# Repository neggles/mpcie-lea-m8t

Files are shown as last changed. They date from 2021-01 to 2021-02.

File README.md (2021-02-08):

# mPCIe-LEA-M8T


This is a little miniPCIe card I designed to hold a [u-blox LEA-M8T](https://www.u-blox.com/en/product/neolea-m8t-series) GNSS module, with an IO header and an optional backup supercap.
The IO header has both timepulse outputs, as well as UART TX/RX. Module USB is connected to miniPCIe USB. I have not included a way to switch from UART to SPI.

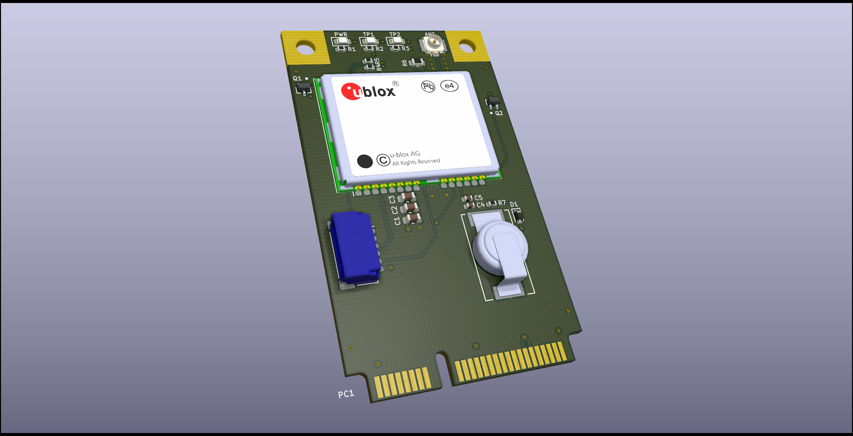
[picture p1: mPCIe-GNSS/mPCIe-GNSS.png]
KiCad raytraced board render


I had this made by [JLCPCB](https://jlcpcb.com) using their 1mm thick PCBs, and elected to get them to assemble most of it - while all of the parts except the supercapacitor, connectors, and GNSS module are in their extended part library, it didn't make sense to spend $6 on extended part fees for two assembled boards, so I skipped the transistors and diode.

## Repository Structure
- `mPCIe-GNSS` contains the main schematics and board drawing
- `mPCIe-GNSS/mPCIe-GNSS.pretty` contains the board-specific footprints
- `mPCIe-GNSS/mPCIe-GNSS-archive.lib` contains the board-specific symbols

## Building
Simply call `make` in the top-top level directory. The `build` directory will
them contain:

- the main mPCIe board
- A panelized version of said board
- zipped gerbers for the boards you can directly use for manufacturing
- zipped gerbers and SMT assembly BOM/position files for JLCPCB's SMT assembly service for the single-board version.

Makefile uses [Jan Mrázek](https://github.com/yaqwsx)'s [KiKit](https://github.com/yaqwsx/KiKit), which I cannot recommend enough, and therefore has to be available on your system.

Jan's [jlcparts](https://yaqwsx.github.io/jlcparts/) app was also extremely useful in narrowing down part choices based on what JLCPCB have available.

-----
### **IMPORTANT NOTE:** If you give JLCPCB these files as-is, *please* verify the orientation of every part before submitting.
Furthermore, while I have received a run of these from JLCPCB, but I appear to have killed my LEA-M8T while 'recovering' it from a chunk of PCB, so **I can't verify that they *actually work***. Will update this if that changes.

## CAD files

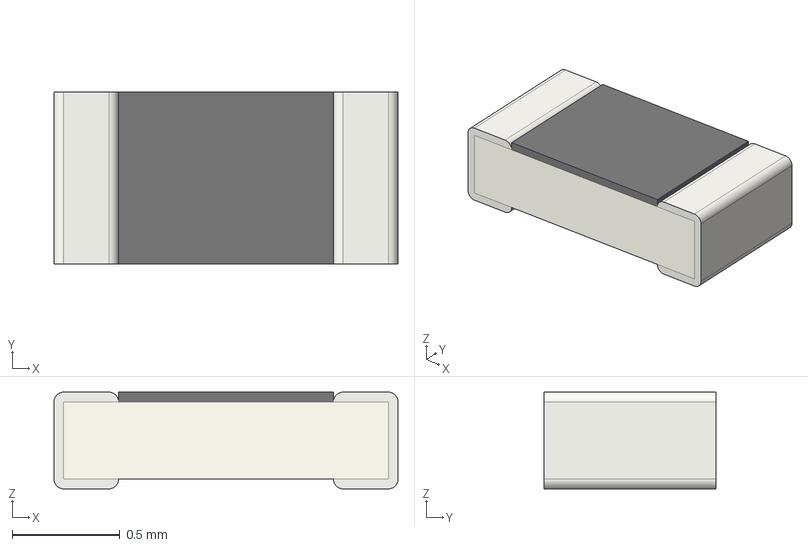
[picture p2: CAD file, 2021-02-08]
mPCIe-GNSS/shapes3D/R_0603_1608Metric.step
1.60 x 0.8 x 0.45 mm

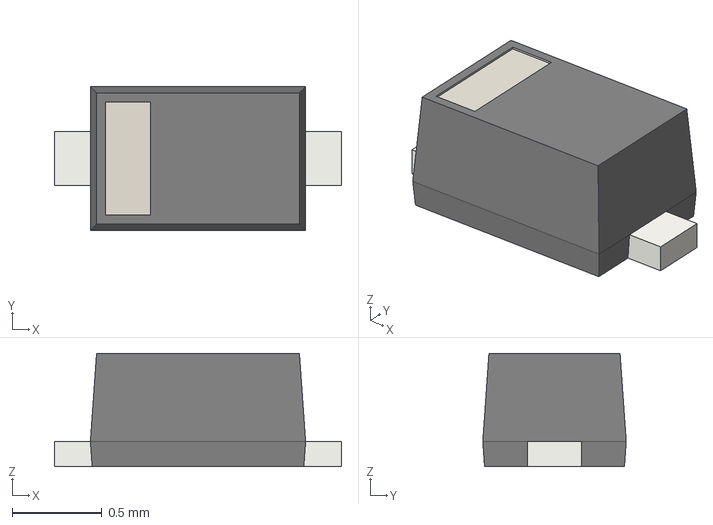
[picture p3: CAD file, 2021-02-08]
mPCIe-GNSS/shapes3D/D_SOD-523.step
1.60 x 0.8 x 0.63 mm

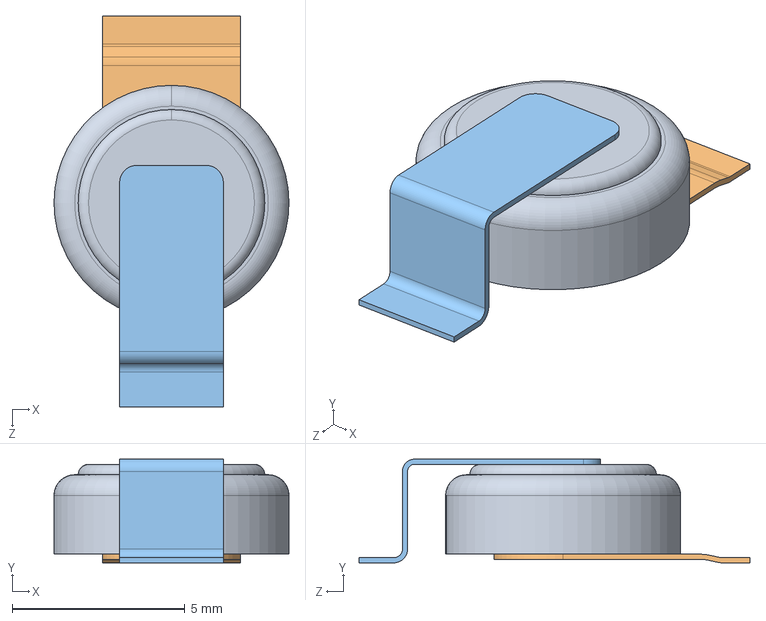
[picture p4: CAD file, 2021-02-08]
mPCIe-GNSS/shapes3D/DSK-3R3H224U-HL.step
6.80 x 3.00 x 11.3 mm

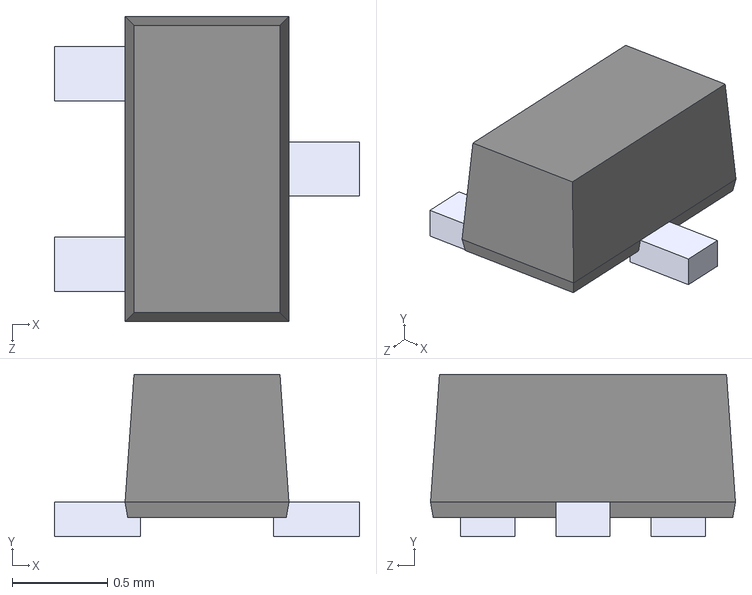
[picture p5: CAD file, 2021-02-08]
mPCIe-GNSS/shapes3D/DTC143ZEBTL.STEP
1.60 x 0.85 x 1.60 mm

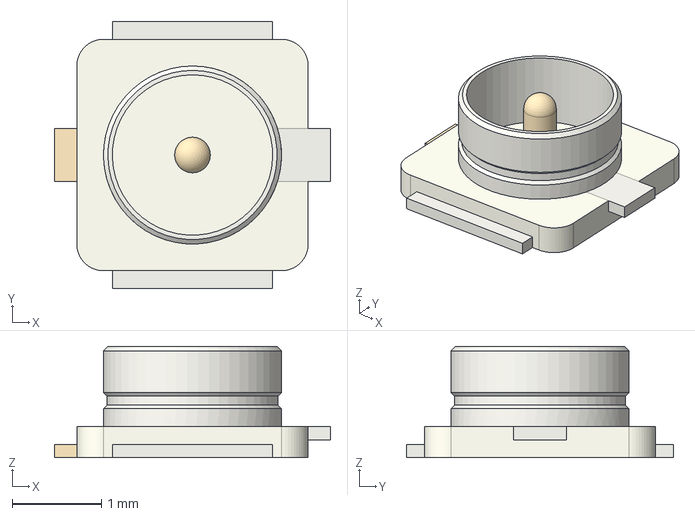
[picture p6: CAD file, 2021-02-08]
mPCIe-GNSS/shapes3D/U.FL_Hirose_U.FL-R-SMT-1_Vertical.step
3.10 x 3.00 x 1.25 mm

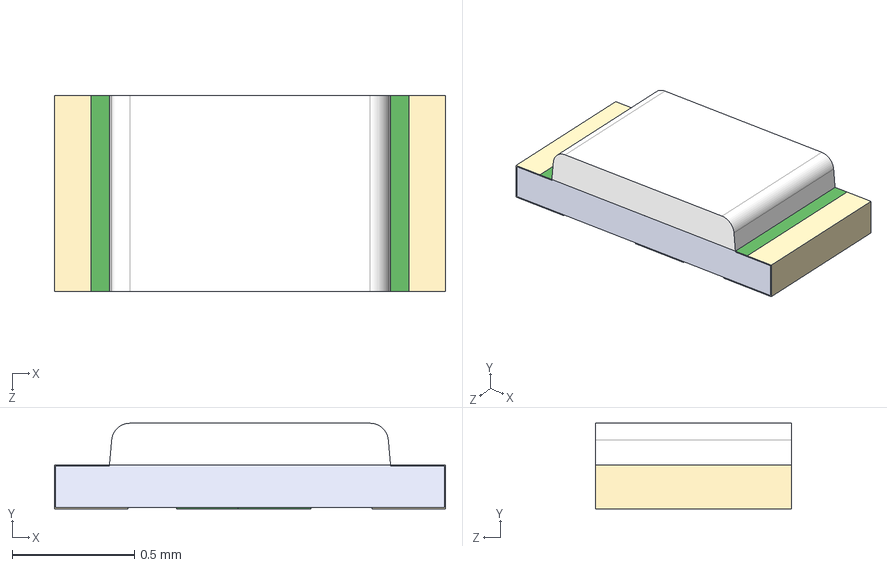
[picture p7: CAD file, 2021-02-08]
mPCIe-GNSS/shapes3D/LTST-C193TBKT-5A.STEP
1.60 x 0.35 x 0.8 mm

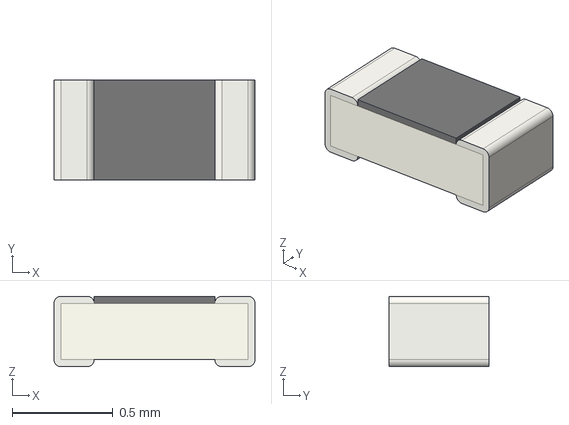
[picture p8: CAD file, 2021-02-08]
mPCIe-GNSS/shapes3D/R_0402_1005Metric.step
1.00 x 0.5 x 0.35 mm

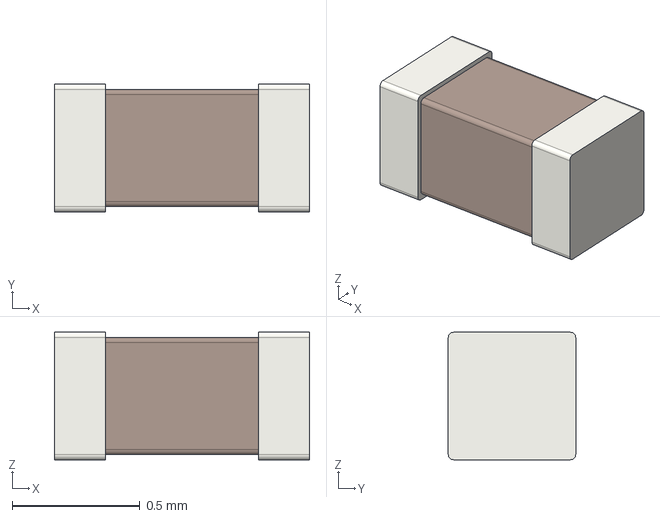
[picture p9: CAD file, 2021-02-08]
mPCIe-GNSS/shapes3D/C_0402_1005Metric.step
1.00 x 0.5 x 0.5 mm

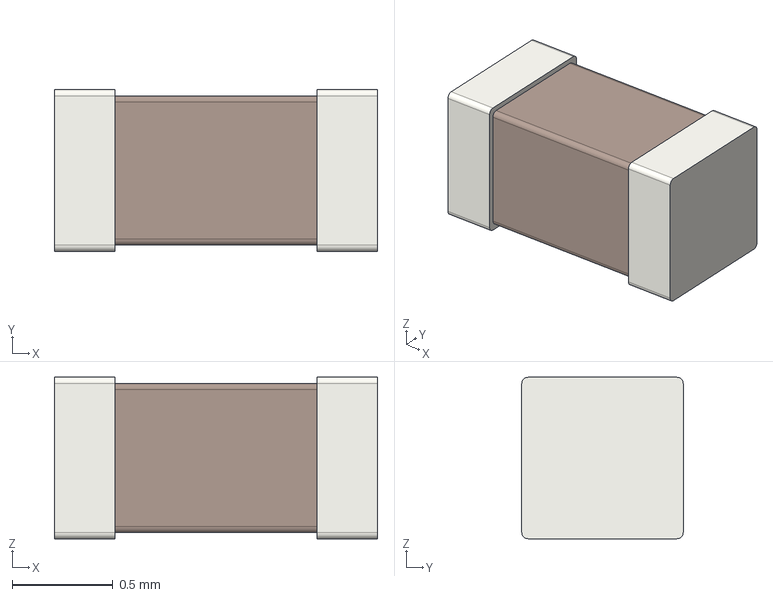
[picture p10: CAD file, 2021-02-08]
mPCIe-GNSS/shapes3D/C_0603_1608Metric.step
1.60 x 0.8 x 0.8 mm

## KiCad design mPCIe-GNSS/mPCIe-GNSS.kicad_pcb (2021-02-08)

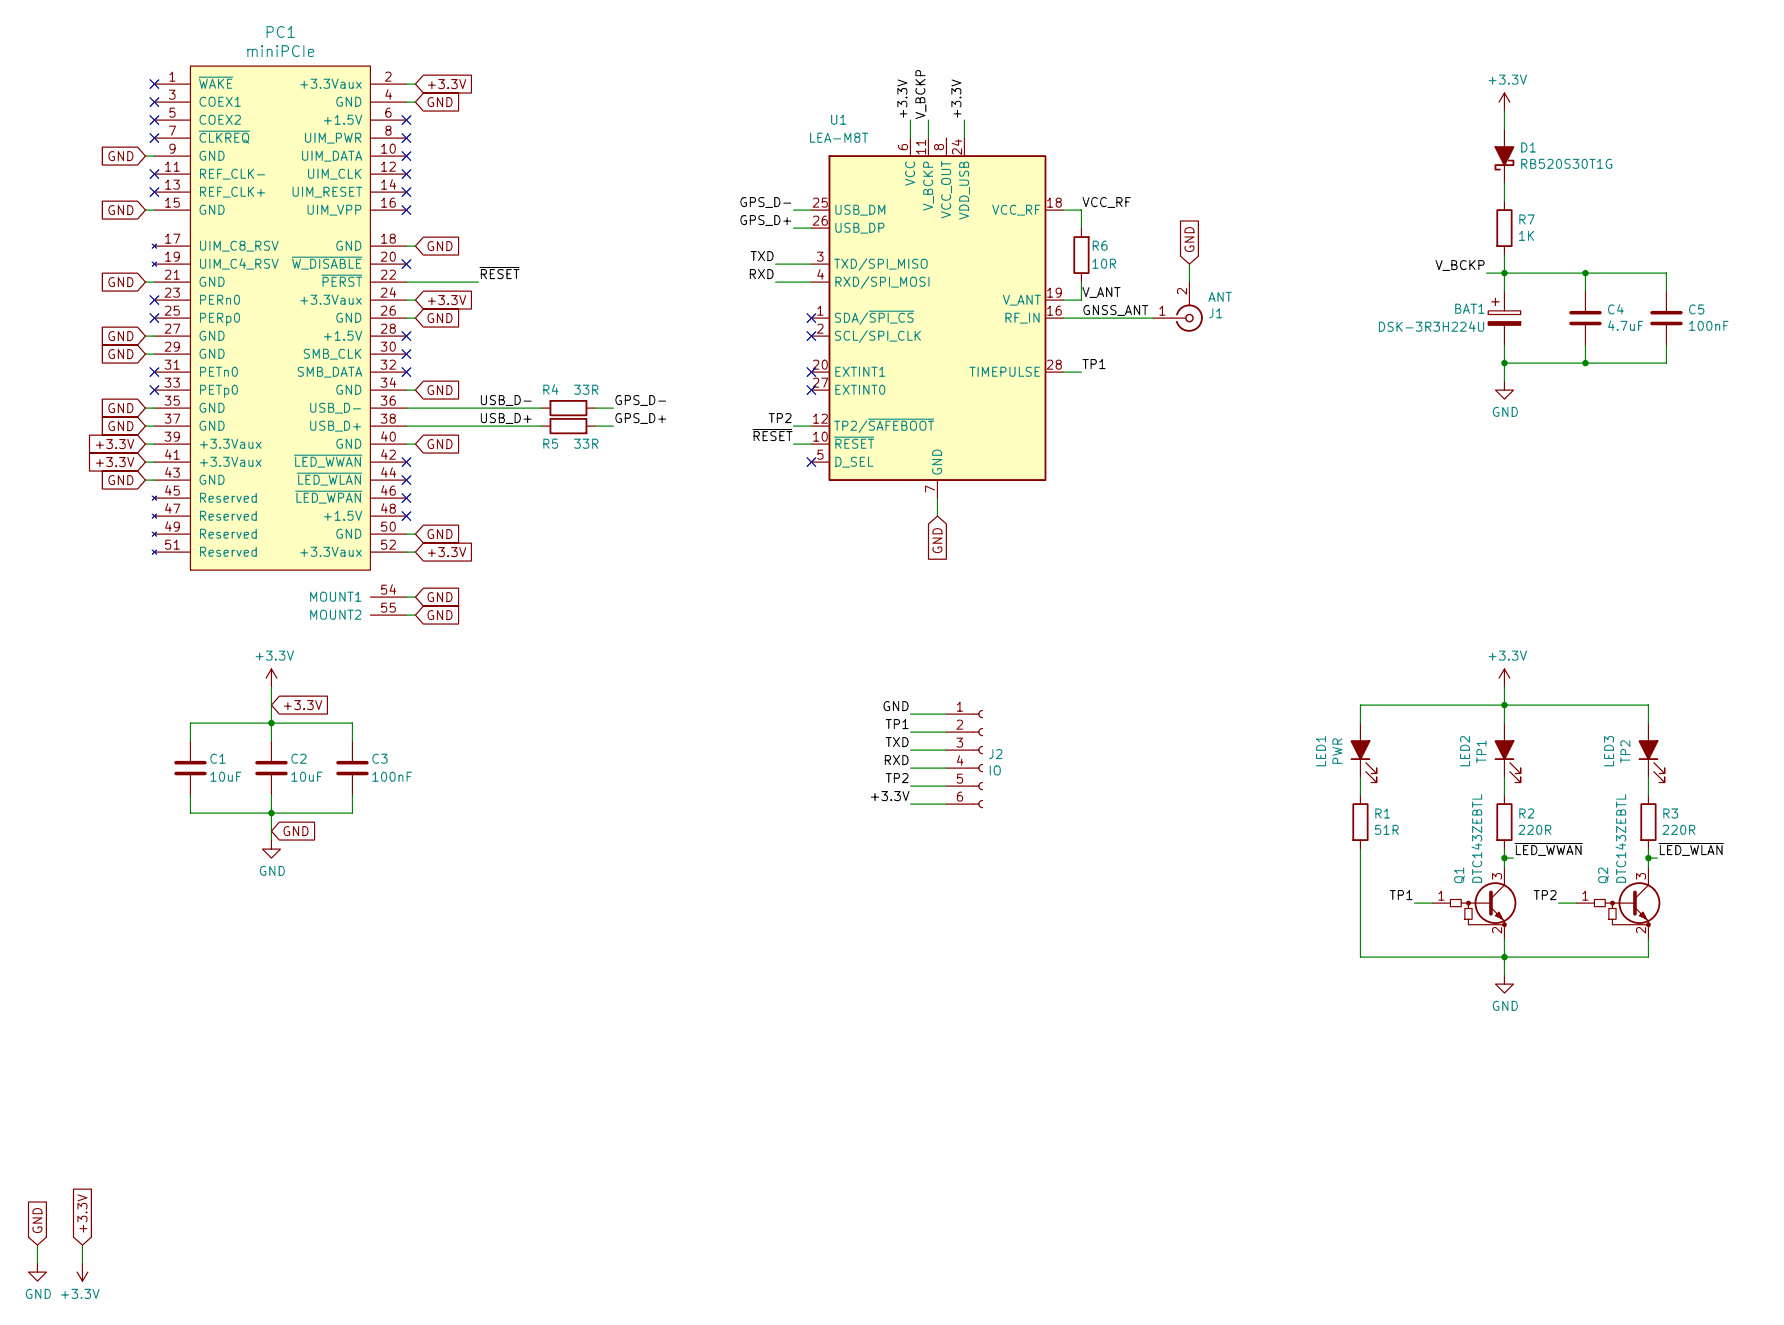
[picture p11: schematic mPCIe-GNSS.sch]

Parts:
BAT1: DSK-3R3H224U; CAP_DSK-3R3H224U-HL
C1, C2: 10uF; C_0603_1608Metric; LCSC C19702
C3: 100nF; C_0603_1608Metric; LCSC C14663
C4: 4.7uF; C_0402_1005Metric; LCSC C23733
C5: 100nF; C_0402_1005Metric; LCSC C1525
D1: RB520S30T1G; D_SOD-523; LCSC C154821
J1: ANT; U.FL_Hirose_U.FL-R-SMT-1_Vertical_Tweaked
J2: IO; JST_SH_SM06B-SRSS-TB_1x06-1MP_P1.00mm_Horizontal_3D
LED1: PWR; LED_0603_1608Metric_SnapModel; LCSC C72041
LED2: TP1; LED_0603_1608Metric_SnapModel; LCSC C72038
LED3: TP2; LED_0603_1608Metric_SnapModel; LCSC C2286
PC1: miniPCIe; mini-PCIe_F1_Full_v517
Q1, Q2: DTC143ZEBTL; Q_EMT3F; LCSC C172398
R1: 51R; R_0402_1005Metric; LCSC C25125
R2, R3: 220R; R_0402_1005Metric; LCSC C25091
R4, R5: 33R; R_0402_1005Metric; LCSC C25105
R6: 10R; R_0603_1608Metric; LCSC C22859
R7: 1K; R_0402_1005Metric; LCSC C11702
U1: LEA-M8T; ublox_LEA; PARTREV R05

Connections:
+3.3V: C1.2, C2.2, C3.1, D1.2 (A), J2.6, LED1.2 (A), LED2.2 (A), LED3.2 (A), PC1.2 (+3.3Vaux), PC1.24 (+3.3Vaux), PC1.39 (+3.3Vaux), PC1.41 (+3.3Vaux), PC1.52 (+3.3Vaux), U1.6 (VCC), U1.24 (VDD_USB)
/GNSS_ANT: J1.1 (In), U1.16 (RF_IN)
/GPS_D+: R5.2, U1.26 (USB_DP)
/GPS_D-: R4.1, U1.25 (USB_DM)
/RXD: J2.4, U1.4 (RXD/SPI_MOSI)
/TP1: J2.2, Q1.1 (B), U1.28 (TIMEPULSE)
/TP2: J2.5, Q2.1 (B), U1.12 (TP2/~SAFEBOOT)
/TXD: J2.3, U1.3 (TXD/SPI_MISO)
/USB_D+: PC1.38 (USB_D+), R5.1
/USB_D-: PC1.36 (USB_D-), R4.2
/VCC_RF: R6.2, U1.18 (VCC_RF)
/V_ANT: R6.1, U1.19 (V_ANT)
/V_BCKP: BAT1.1, C4.1, C5.1, R7.2, U1.11 (V_BCKP)
/~LED_WLAN: Q2.3 (C), R3.2
/~LED_WWAN: Q1.3 (C), R2.2
/~RESET: PC1.22 (~PERST), U1.10 (~RESET)
GND: BAT1.2, C1.1, C2.1, C3.2, C4.2, C5.2, J1.2 (Ext), J2.1, PC1.4 (GND), PC1.9 (GND), PC1.15 (GND), PC1.18 (GND), PC1.21 (GND), PC1.26 (GND), PC1.27 (GND), PC1.29 (GND), PC1.34 (GND), PC1.35 (GND), PC1.37 (GND), PC1.40 (GND), PC1.43 (GND), PC1.50 (GND), PC1.54 (MOUNT1), PC1.55 (MOUNT2), Q1.2 (E), Q2.2 (E), R1.2, U1.7 (GND), U1.13 (GND), U1.14 (GND), U1.15 (GND), U1.17 (GND)
unnamed: D1.1 (K), R7.1
unnamed: LED1.1 (K), R1.1
unnamed: LED2.1 (K), R2.1
unnamed: LED3.1 (K), R3.1

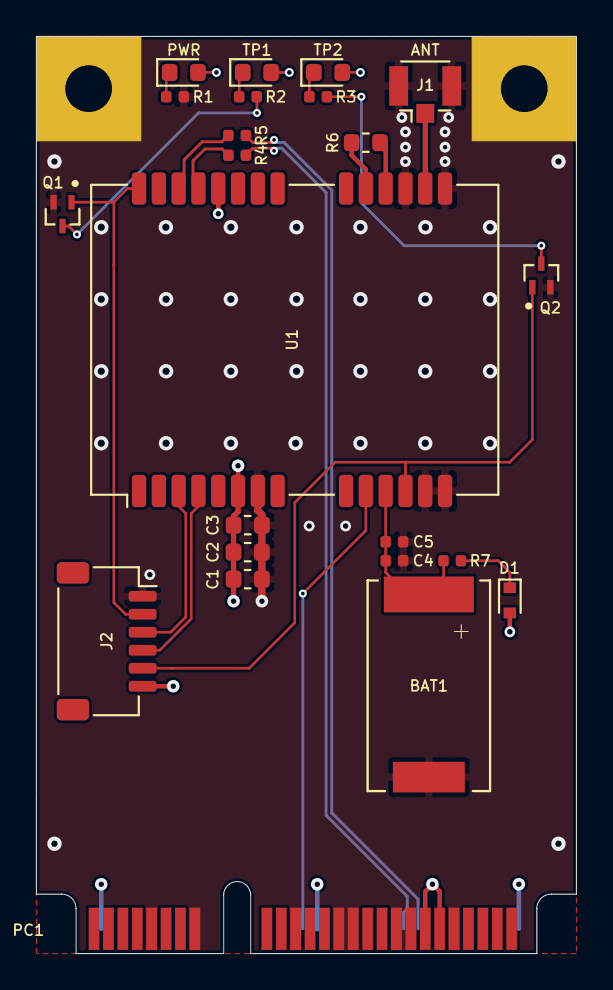
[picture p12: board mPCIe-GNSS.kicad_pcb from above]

Board: 4 copper layers, 30.0 x 51.0 mm, 23 parts (0 on the bottom side), 21 nets.

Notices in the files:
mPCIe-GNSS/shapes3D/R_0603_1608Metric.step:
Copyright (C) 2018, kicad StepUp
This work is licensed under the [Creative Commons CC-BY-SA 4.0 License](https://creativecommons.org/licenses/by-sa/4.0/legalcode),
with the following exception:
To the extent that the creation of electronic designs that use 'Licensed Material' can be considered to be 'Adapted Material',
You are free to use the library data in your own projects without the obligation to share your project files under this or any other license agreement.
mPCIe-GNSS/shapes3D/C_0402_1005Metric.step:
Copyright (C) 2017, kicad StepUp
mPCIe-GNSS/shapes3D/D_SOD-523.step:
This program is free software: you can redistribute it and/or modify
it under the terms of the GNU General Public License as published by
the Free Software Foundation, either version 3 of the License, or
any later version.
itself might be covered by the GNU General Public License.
